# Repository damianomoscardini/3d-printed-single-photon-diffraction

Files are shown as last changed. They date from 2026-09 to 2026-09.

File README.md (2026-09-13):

# 3D-printed "single-photon" diffraction

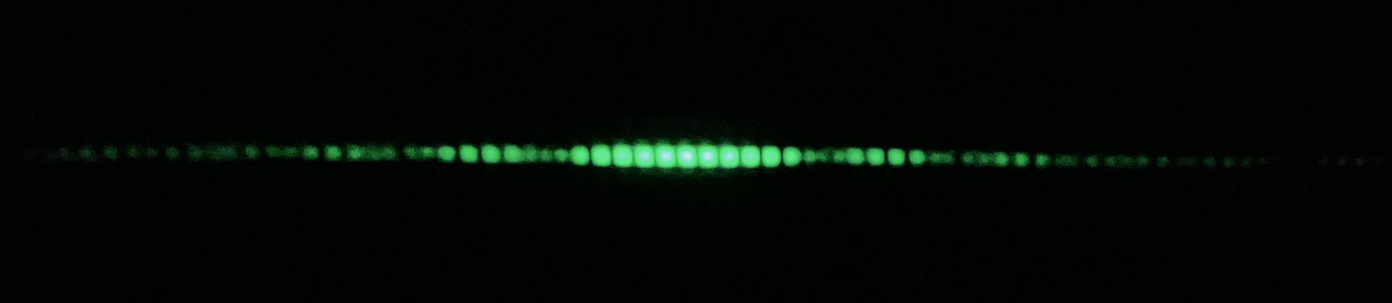
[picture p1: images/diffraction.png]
Double-slit diffraction pattern


A home-built double-slit diffraction experiment in the "single-photon" regime — laser, filters, slits, and every mount that holds them — printed on a stock, budget FDM printer (Creality Ender 3), for a fraction of the cost of a lab-grade setup. Shown at a couple of student conferences.

The experiment itself — apparatus, physics, and results — is described in [`materials/`](materials/) (poster and conference presentation), not in this README.

## Repository layout

```
high_intensity_fit.py        minima-position fit for the high-intensity pattern
single_photon_fit.py         intensity-profile fit for the "single-photon" pattern
acquisitions/                curated scans: the 3 quantitative patterns + 3 extra geometries
images/                      diffraction.png, shown above
3d files/                    3D-printable parts (STL, DWG)
materials/                   poster.pdf and presentation.pdf — the full writeup
```

## Analysis code

Two self-contained scripts reproduce the two quantitative results — cleaned-up, English versions of the Python scripts originally used to analyze these patterns. Each one prints its fit results and saves a figure.

- [`high_intensity_fit.py`](high_intensity_fit.py): fits hand-identified minima positions against fringe order (needed for the high-intensity pattern, whose saturated peaks rule out a direct intensity fit).
- [`single_photon_fit.py`](single_photon_fit.py): fits the whole intensity profile directly against the theoretical Fraunhofer intensity (used for the "single-photon" pattern).

```bash
python high_intensity_fit.py
python single_photon_fit.py
```

### Requirements & setup

The project targets Python 3.12. The exact dependency list used in the provided dev container is in [`.devcontainer/Dockerfile`](.devcontainer/Dockerfile); the core packages are:

```
numpy scipy matplotlib pillow
```

Easiest path: open the repository in the provided dev container (`.devcontainer/`), which builds a ready-to-use image with everything installed. Alternatively, install the packages above with pip in your own environment and run the scripts directly.

## License

Code (`high_intensity_fit.py`, `single_photon_fit.py`) is licensed under the [GNU GPLv3](LICENSE). The image (`images/`) and the 3D-printable files (`3d files/`) are licensed separately under CC BY-SA 4.0 — see [`3d files/LICENSE`](3d%20files/LICENSE). `materials/poster.pdf` and `materials/presentation.pdf` are included for reference only and are not covered by either license.

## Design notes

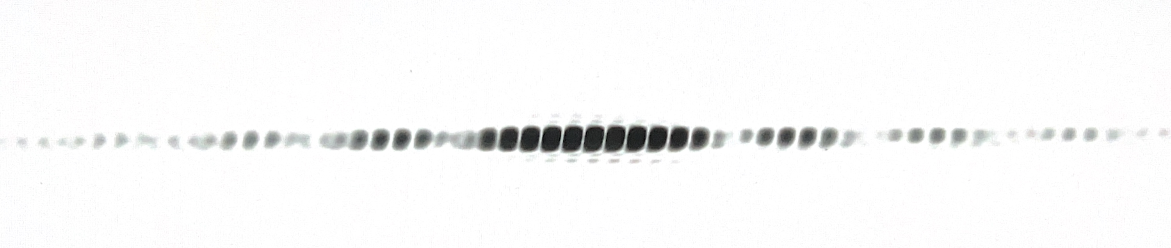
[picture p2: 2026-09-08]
acquisitions/double-slit/pattern.jpg

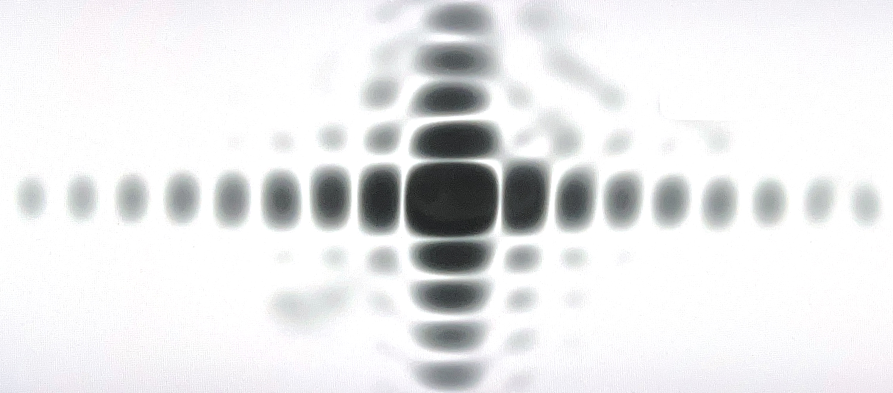
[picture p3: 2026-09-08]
acquisitions/square/pattern.jpg

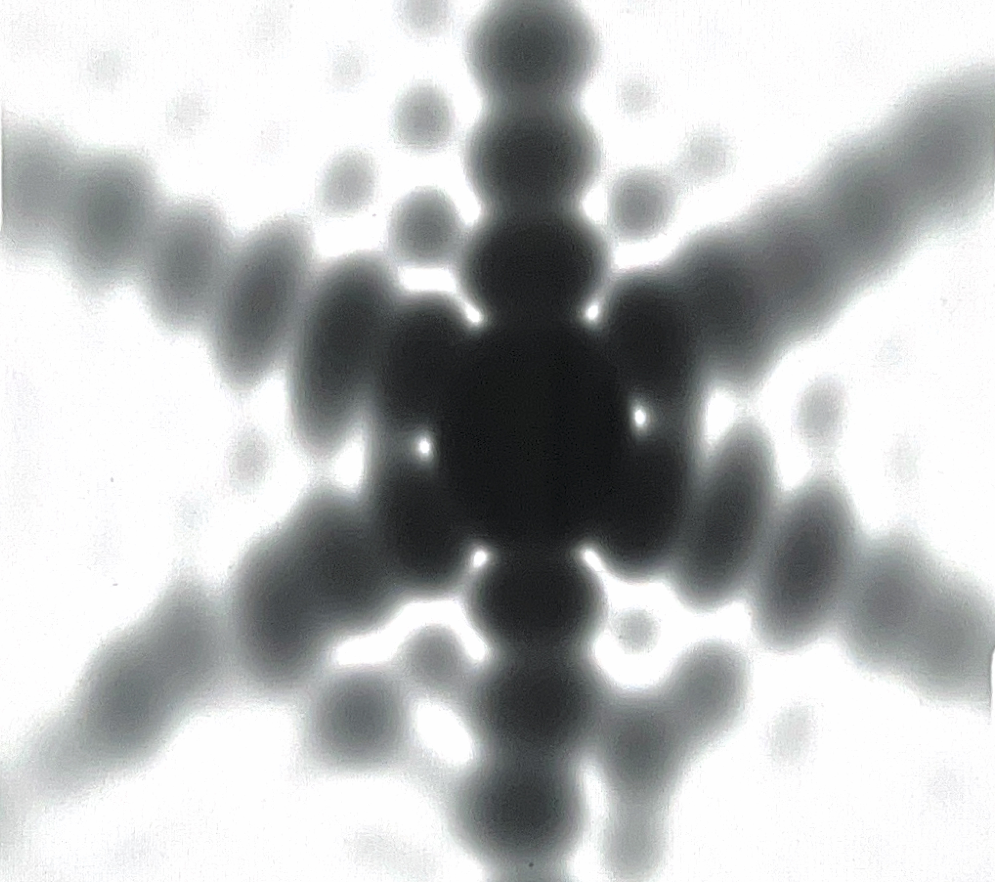
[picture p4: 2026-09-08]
acquisitions/triangle/pattern.jpg

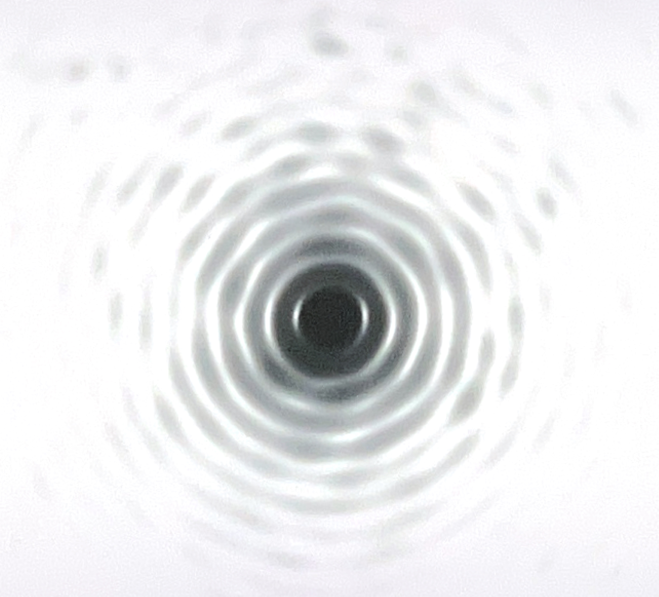
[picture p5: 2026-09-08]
acquisitions/circle/pattern.jpg

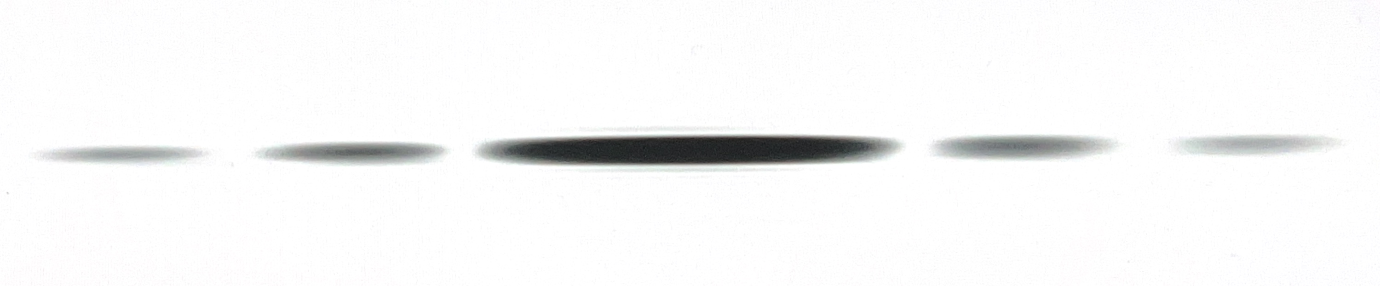
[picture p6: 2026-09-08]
acquisitions/single-slit/pattern.jpg

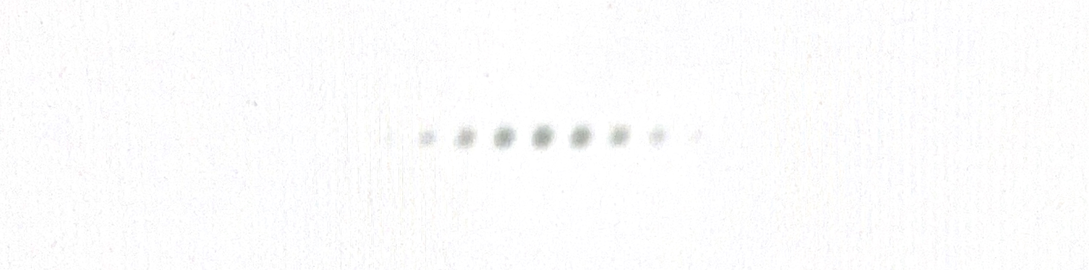
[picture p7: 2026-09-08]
acquisitions/double-slit-single-photon/pattern.jpg

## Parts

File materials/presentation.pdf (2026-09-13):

# A «single-photon» diffraction experiment built at home using a

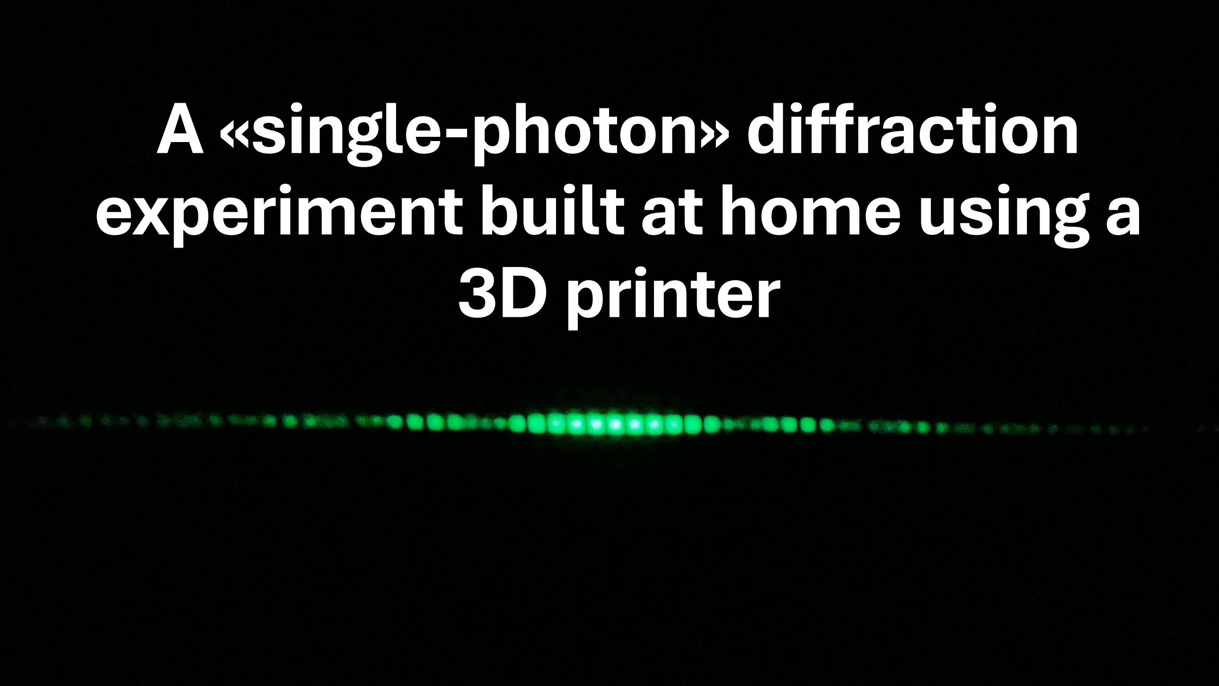
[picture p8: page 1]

# 3D printer

## Experimental setup

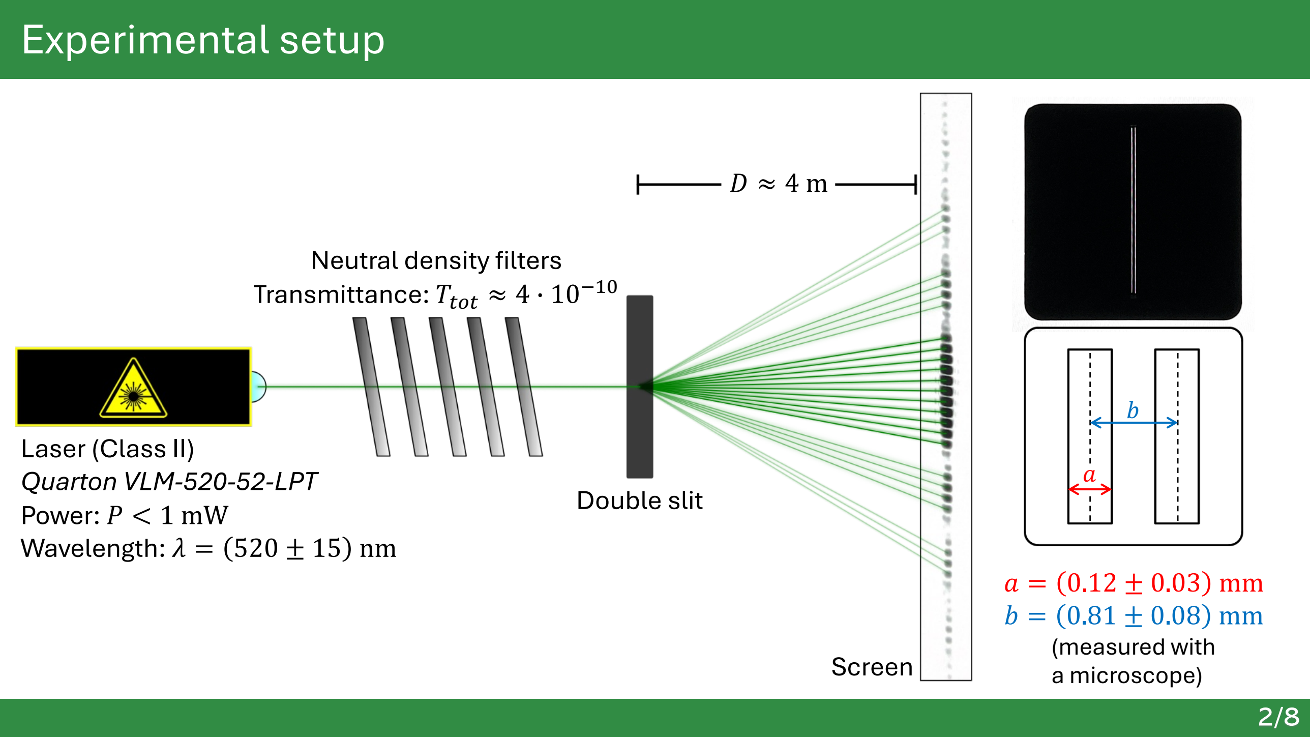
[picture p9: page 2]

Screen

Double slit

Neutral density filters
Transmittance: T!"! ≈ 4 $ 10#$%

Laser (Class II)
Quarton VLM-520-52-LPT
Power: P < 1 mW
Wavelength: λ = 520 ± 15 nm a = 0.12 ± 0.03 mm
b = 0.81 ± 0.08 mm
(measured with
a microscope)

b

a

Type
equation
here.

D ≈ 4 m

## Photos of the equipment

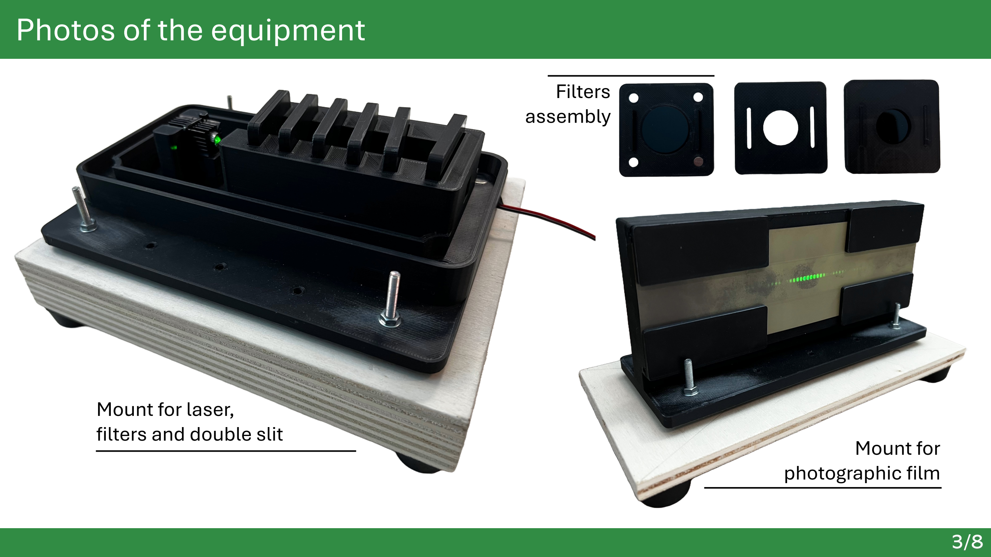
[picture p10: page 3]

Mount for
photographic film

Filters
assembly

Mount for laser,
filters and double slit

## «Single-photon» regime

S N < 0.02 > 99%

P n =

N& $ e#'
n! Probability of having n photons per path[1]:

Fraction of single photons among all emitted photons: S N =

P n = 1
P n ≥ 1

=

P 1
1 − P 0

=

Ne#'
1 − e#'

Mean number of photons per path: N =

E()*+,
E-

$ T!"! =

P $ Δt
ℎ $ ν $ T!"! =

P $

D
c
ℎ $

c
λ

$ T!"! =

P $ D $ λ
ℎ $ c. $ T!"! < 0.02
- Laser power: P < 1 mW
- Screen distance: D ≈ 4 m
- Laser wavelength: λ < 535 nm
- Total transmittance of the filters: T!"! ≈ 4 > 10#$%
- Planck constant: ℎ ≈ 6.6 > 10#&' J > s
- Speed of light in air: c ≈ 2.99 > 10⁽ m/s

## Results in the high-intensity regime

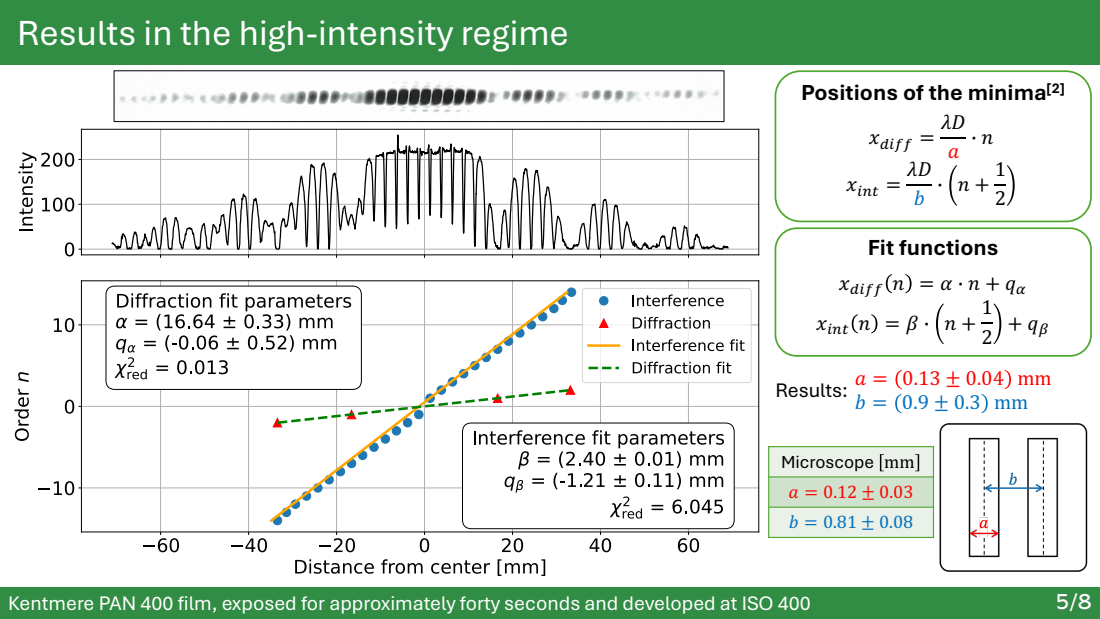
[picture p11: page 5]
Fit functions; Results:; Microscope

Positions of the minima[2]

Kentmere PAN 400 film, exposed for approximately forty seconds and developed at ISO 400

## Risultati in regime di singoli fotoni

## Results in the «single-photon» regime

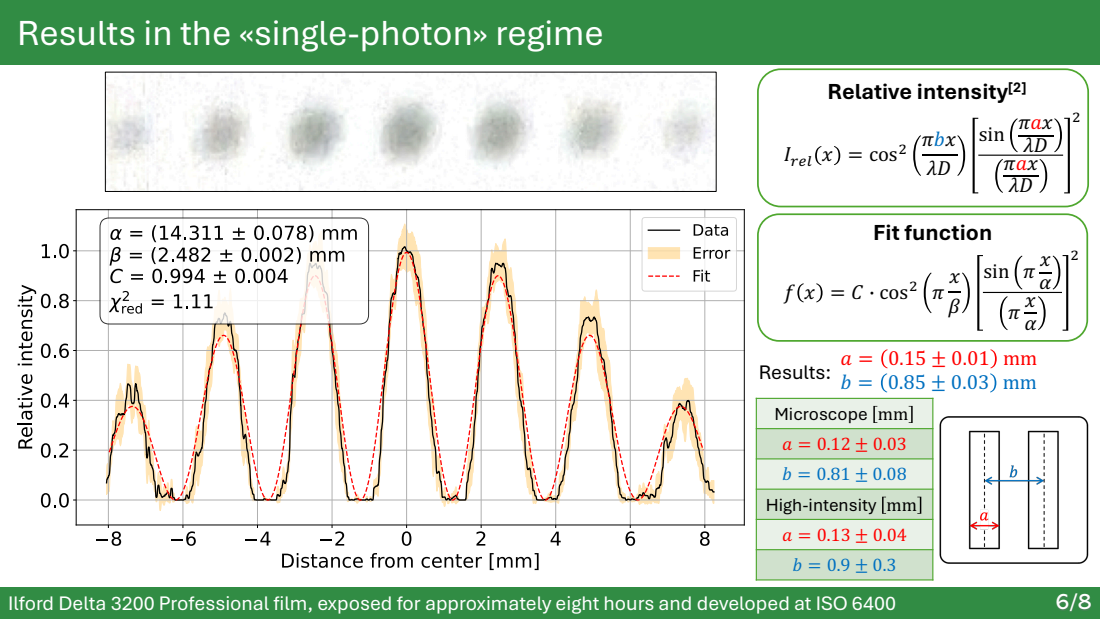
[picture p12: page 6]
Fit function; Relative intensity[2]; I/01 x = cos² πbx λD; sin πax λD πax λD; f x = C > cos² π; sin π; Microscope; High-intensity; a = 0.15 ± 0.01 mm b = 0.85 ± 0.03 mm Results:

Ilford Delta 3200 Professional film, exposed for approximately eight hours and developed at ISO 6400

## Bonus: further diffraction patterns

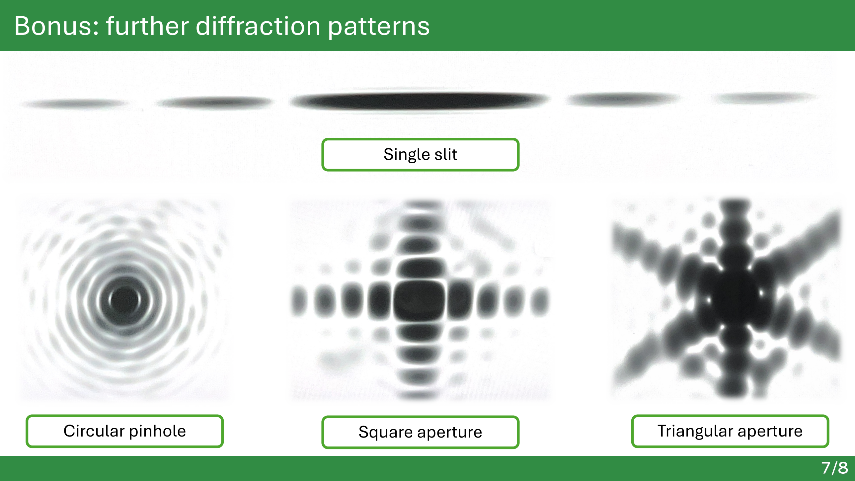
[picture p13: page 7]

Single slit

Circular pinhole | Square aperture | Triangular aperture

## References

[1] Alan Migdall, Sergey V. Polyakov, Jingyun Fan, and Joshua C. Bienfang, editors. Single-Photon Generation and Detection: Physics and Applications. Academic Press, 2013.
[2] Eugene Hecht. Optics. Pearson, 5th edition, 2016.

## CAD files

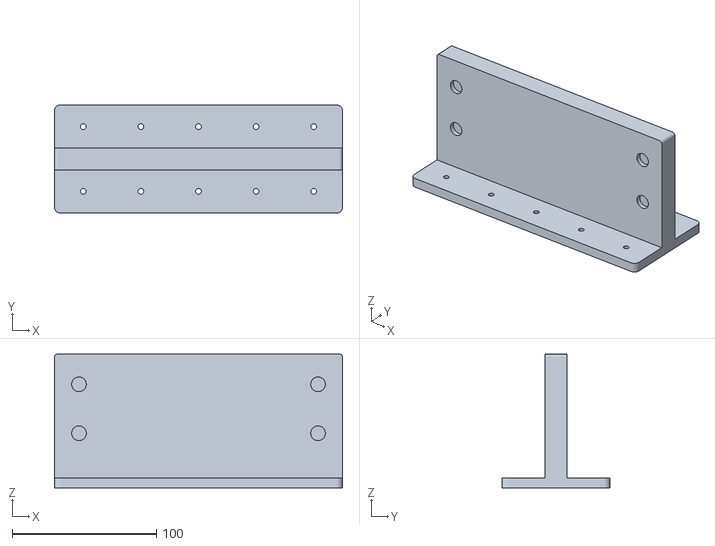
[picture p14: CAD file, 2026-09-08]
3d files/film holder/main.stl
200.0 x 75.0 x 93.0

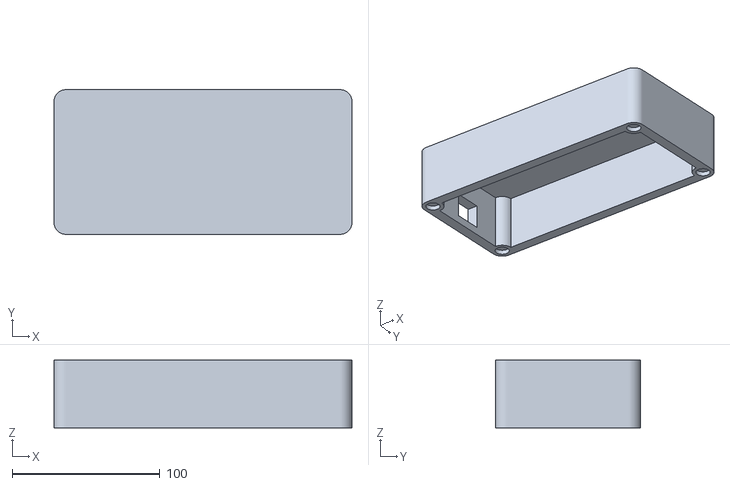
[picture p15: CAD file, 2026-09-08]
3d files/apparatus/lid.stl
201.8 x 98.0 x 46.0

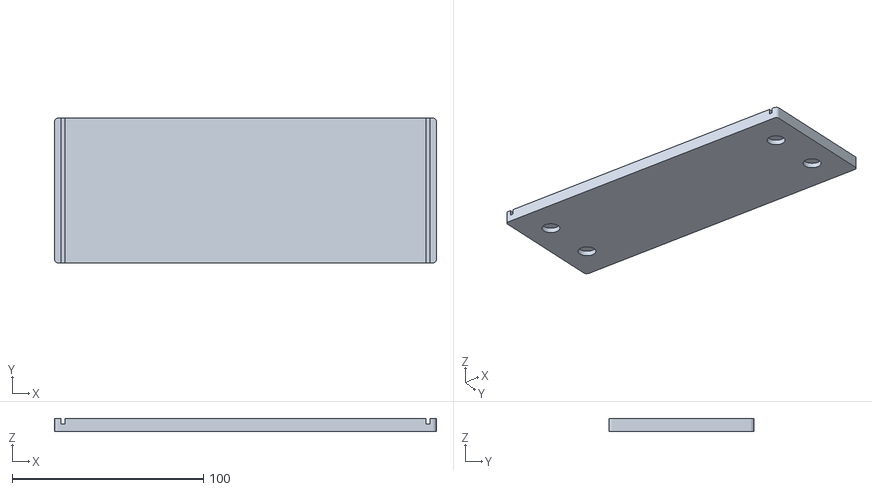
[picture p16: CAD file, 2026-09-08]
3d files/film holder/vertical base.stl
200.0 x 76.0 x 7.00

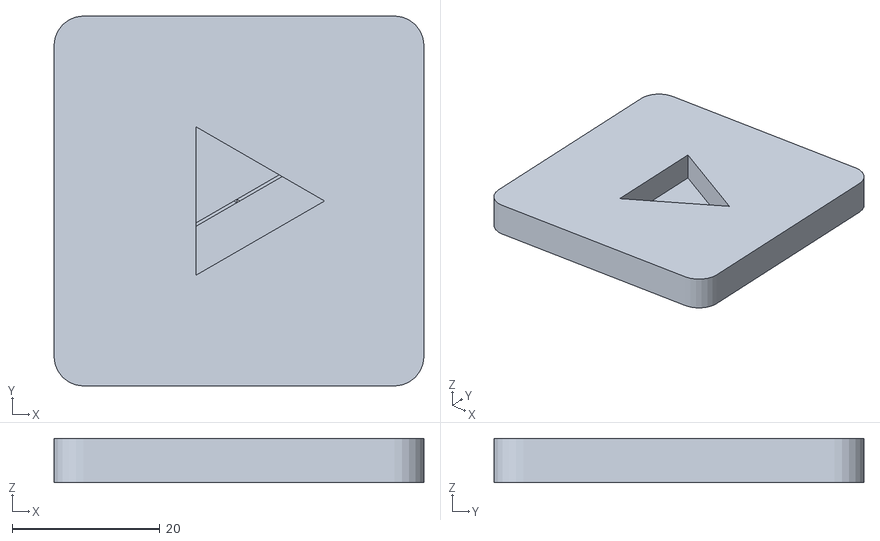
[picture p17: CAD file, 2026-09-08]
3d files/slits/triangular aperture.stl
50.0 x 50.0 x 6.00

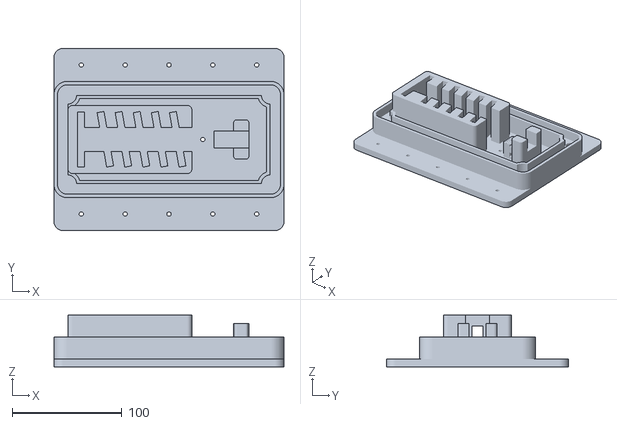
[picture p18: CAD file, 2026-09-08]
3d files/apparatus/base.stl
209.8 x 166.0 x 47.0

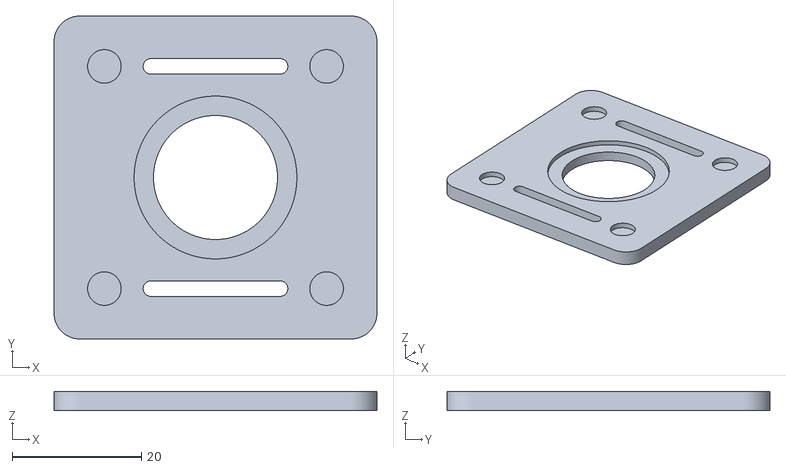
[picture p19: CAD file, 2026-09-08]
3d files/apparatus/filter part 2.stl
50.0 x 50.0 x 3.00

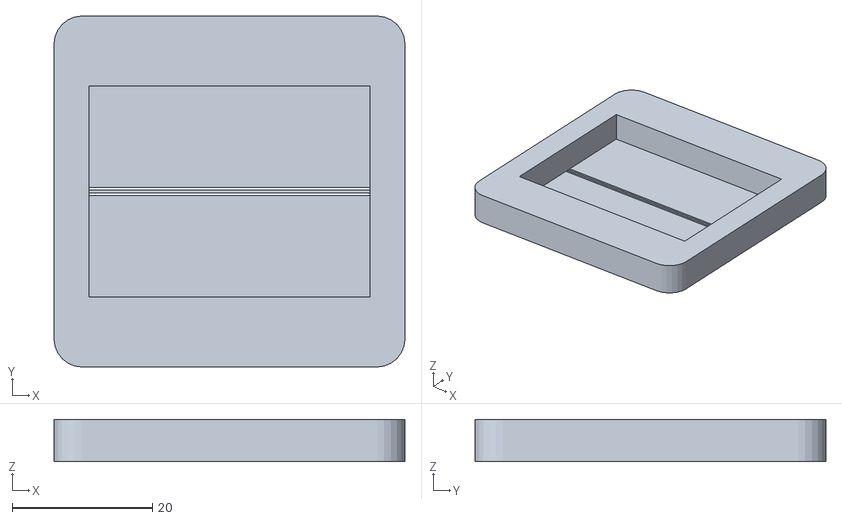
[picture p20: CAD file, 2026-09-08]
3d files/slits/double slit.stl
50.0 x 50.0 x 6.00

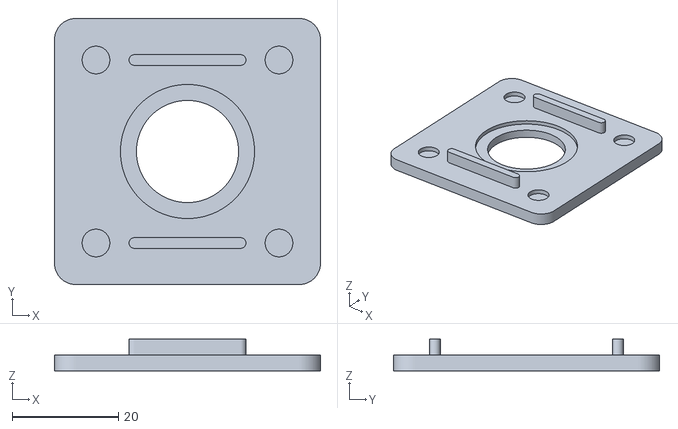
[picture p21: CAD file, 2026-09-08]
3d files/apparatus/filter part 1.stl
50.0 x 50.0 x 6.00

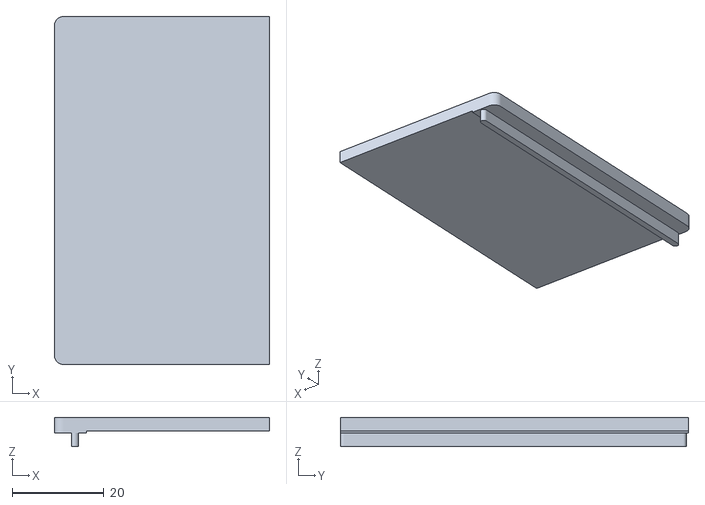
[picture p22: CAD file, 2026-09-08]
3d files/film holder/vertical holder.stl
47.0 x 76.0 x 6.40

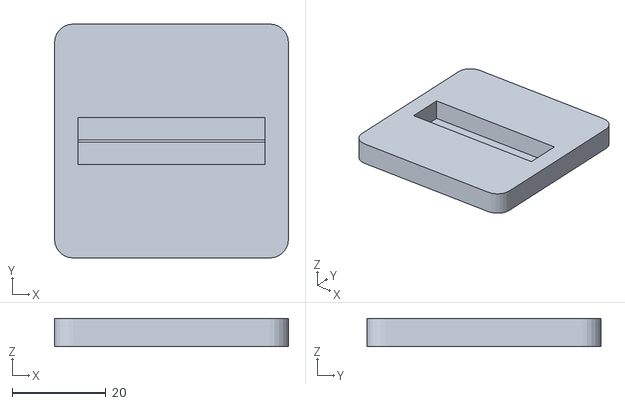
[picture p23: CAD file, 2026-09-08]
3d files/slits/single slit.stl
50.0 x 50.0 x 6.00

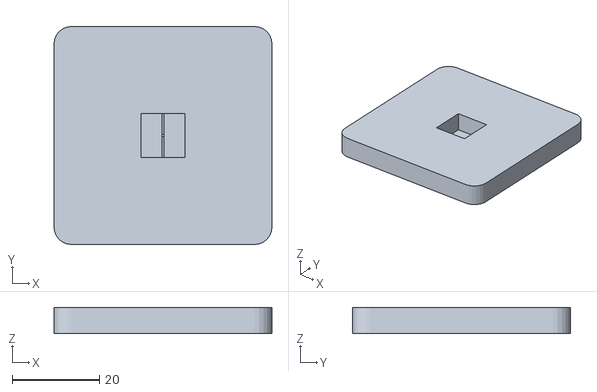
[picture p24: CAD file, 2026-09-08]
3d files/slits/square aperture.stl
50.0 x 50.0 x 6.00

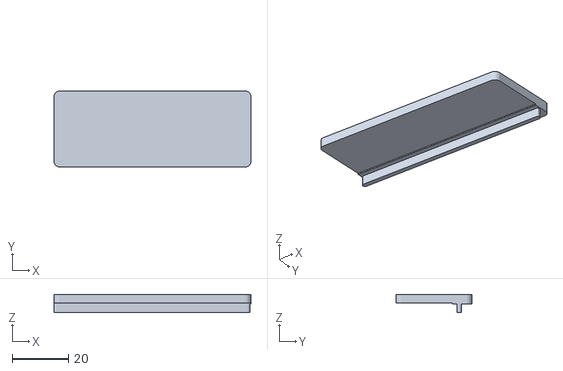
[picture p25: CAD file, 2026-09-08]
3d files/film holder/horizontal holder.stl
70.0 x 27.0 x 6.40

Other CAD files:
3d files/slits/slits.dwg
3d files/apparatus/apparatus.dwg
3d files/film holder/film holder.dwg
3d files/slits/pinhole.stl
3d files/film holder/horizontal base.stl

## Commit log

2026-09-08 First commit.
    [apparato.dwg, apparato_1.dwg, apparato_2.dwg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]
2026-09-08 Organized 3d files folder.
    [apparato.dwg, apparato_1.dwg, apparato_2.dwg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]
